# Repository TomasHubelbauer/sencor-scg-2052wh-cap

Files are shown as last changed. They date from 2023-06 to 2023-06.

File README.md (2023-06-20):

# Sencor SCG 2052WH Cap

This repository hosts the source code for a 3D model of the Sencor SCG 2052WH
coffee grinder cap.

https://www.sencor.com/electric-coffee-grinder/scg-2052

The purpose of this model is to be used for 3D printing a replacement cap as the
factory one has interlocking flaps that are very much prone to breaking.

I recommend printing the replacement cap in transparent filament to preserve the
ability to see the status of the ground coffee without taking the lid off.

This is a work in progress, see the `TODO` comments in the OpenSCAD script to
see what is left to do.

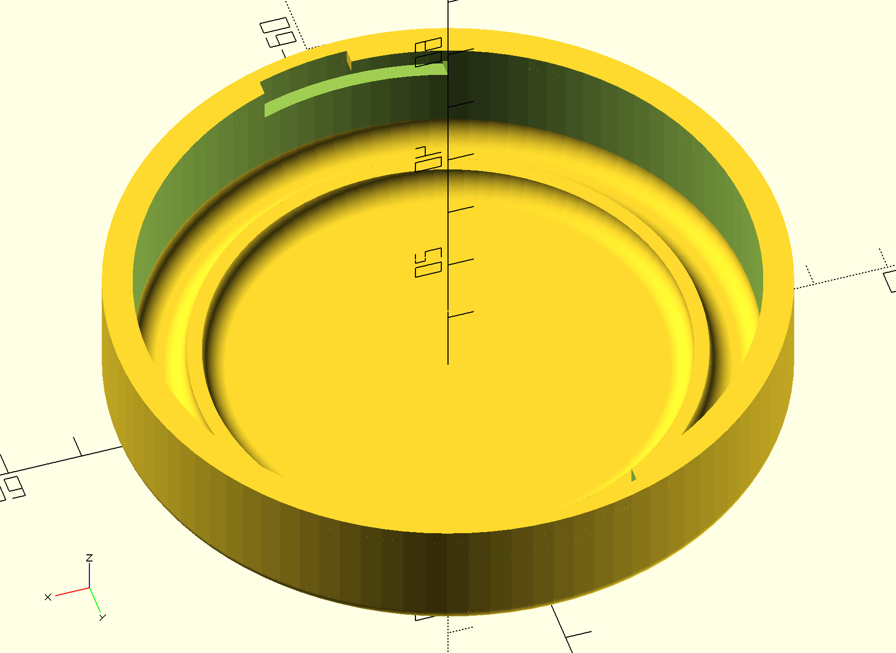
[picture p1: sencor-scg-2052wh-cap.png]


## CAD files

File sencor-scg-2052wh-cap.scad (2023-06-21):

outer_diameter = 90;
outer_radius = outer_diameter / 2;
inner_diameter = 82;
inner_radius = inner_diameter / 2;
height = 17;
slit_length = 25;
slit_depth = outer_radius - inner_radius - 2;
slit_height = 5;
flap_height = 2;

epsilon = 0.1;

use <openscad-quarter-circle-torus/quarter-circle-torus.scad>

// Make cylinders super duper smooth
$fn = 100;

// Cut out the inner cylinder out of the outer one to make the cap lip ring
difference() {
  translate([0, 0, 2])
  // The cylinder representing the outer wall of the cap
  cylinder(height - 2, outer_radius, outer_radius);

  // Shift the cutout cylinder up to make the thin window at the top of the lid
  translate([0, 0, .4])

  // The cylinder representing the inner wall of the cap
  cylinder(height + 2 + epsilon, inner_radius, inner_radius);

  // Cut out the slits on the opposite sides by intersecting the mid cylinder
  translate([0, 0, .4])
  intersection() {
    // The cylinder representing the mid wall of the cap at the slit depth
    cylinder(height, inner_radius + slit_depth, inner_radius + slit_depth);

    translate([-slit_length / 2, -outer_radius, height - slit_height])
    // A cube that cuts into the mid cylinder to make the opposite side slits
    cube([slit_length, outer_radius * 2, height]);
  }
}

// TODO:
// - Add ramps to the slids instead of straight walls to make putting the lid on
//   easier
// - Find a way to taper the whole geometry so that it gets narrower towards the
//   top and looks more robust
// - Smooth out the edge of the top of the lid so it is nicer to handler by hand
//   by rotate extruding a quarter circle and excluding it from the lid and then
//   adding it to the inner side of the lid to make the wall thickness constant
// - Add an epsilon to the flaps so that the Z fighting does not appear in the
//   preview render

translate([0, 0, height - flap_height])
intersection() {
  difference() {
    // The cylinder representing the outer wall of the cap
    cylinder(flap_height, outer_radius, outer_radius);

    // The cylinder representing the inner wall of the cap
    translate([0, 0, -epsilon])
    cylinder(flap_height + epsilon * 2, inner_radius, inner_radius);
  }

  group() {
    translate([-slit_length / 2, -outer_radius, 0])
    cube([slit_length / 2, outer_radius, flap_height]);

    translate([0 / 2, 0, 0])
    cube([slit_length / 2, outer_radius, flap_height]);
  }
}

difference() {
  cylinder(4, 68 / 2, 68 / 2);

  translate([0, 0, .4])
  cylinder(4, 64 / 2, 64 / 2);
}

side = 3;
translate([0, 0, 1 + side / 2])
inverted_quarter_torus(side = side, radius = (64 - side) / 2, quadrant = 1, $fn = 100);

translate([0, 0, 1 + side / 2])
inverted_quarter_torus(side = side, radius = (inner_diameter - side) / 2, quadrant = 1, $fn = 100);

translate([0, 0, 1 + side / 2])
inverted_quarter_torus(side = side, radius = (68 + side) / 2, quadrant = 0, $fn = 100);

cylinder(1, inner_radius + 2, inner_radius + 2);

translate([0, 0, 2 / 2])
quarter_torus(side = 2, radius = outer_radius - 2 / 2, quadrant = 1, $fn = 100);

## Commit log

2023-06-20 Describe the purpose of the repository and link the coffee grinder
    I've linked the original manufacturer's website instead of the store I got it at as that link will presumably stay current much longer.
2023-06-20 Capture the first version of the geometry
    This should be the right general shape but some quality of life improvements still need to be done to make it overall nicer looking.
    [sencor-scg-2052wh-cap.scad]
2023-06-20 Add rounded edges to where the walls meet the planes
    I have softened the entire model a little bit using the library I made for generating quarter tori.
    [sencor-scg-2052wh-cap.scad]
2023-06-20 Drop the height of the internal wall to a half of the assembly
    This looks better.
    [sencor-scg-2052wh-cap.scad]
2023-06-21 Add epsilon to make the slits not have any Z-fighting
    Looks better in the preview mode.
    [sencor-scg-2052wh-cap.scad]
2023-06-21 Swap the orientation of the slit flaps to copy the shape of the original lid
    I put these in the other way around which is incompatible with how the coffe grinder body slots to the lid.
    [sencor-scg-2052wh-cap.scad]
2023-06-21 Ignore STL and GCODE files
    I don't think I wanna keep these in the repository for now.
2023-06-21 Make the internal wall shorter to match the real product
    I think this was rubbing against the body of the grinder.
    [sencor-scg-2052wh-cap.scad]
2023-06-21 Make the cap top thicker to print better
    The single layer vibe wasn't coming out very well after the printing and I think in general this part will need to be stronger and should still be see through with transparent PLA.
    [sencor-scg-2052wh-cap.scad]
2023-06-21 Make the sort ring edges thicker and bring down internal wall to meet them
    I think this looks a bit better.
    [sencor-scg-2052wh-cap.scad]
